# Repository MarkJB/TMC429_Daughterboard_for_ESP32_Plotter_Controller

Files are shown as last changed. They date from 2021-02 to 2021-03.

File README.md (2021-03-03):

# TMC429 Daughterboard for ESP32 Plotter Controller
 
Released under an MIT licence, no warranty implied or given, use at own risk etc etc.

This is an add-on (daughterboard) for the ESP32 Plotter Controller board (Rev A) to evaluate the TMC429 motion controller chip using the TMC429 Break-out-board.

Firmware TBD

[Schematic]( https://github.com/MarkJB/TMC429_Daughterboard_for_ESP32_Plotter_Controller/blob/master/schematic.pdf )

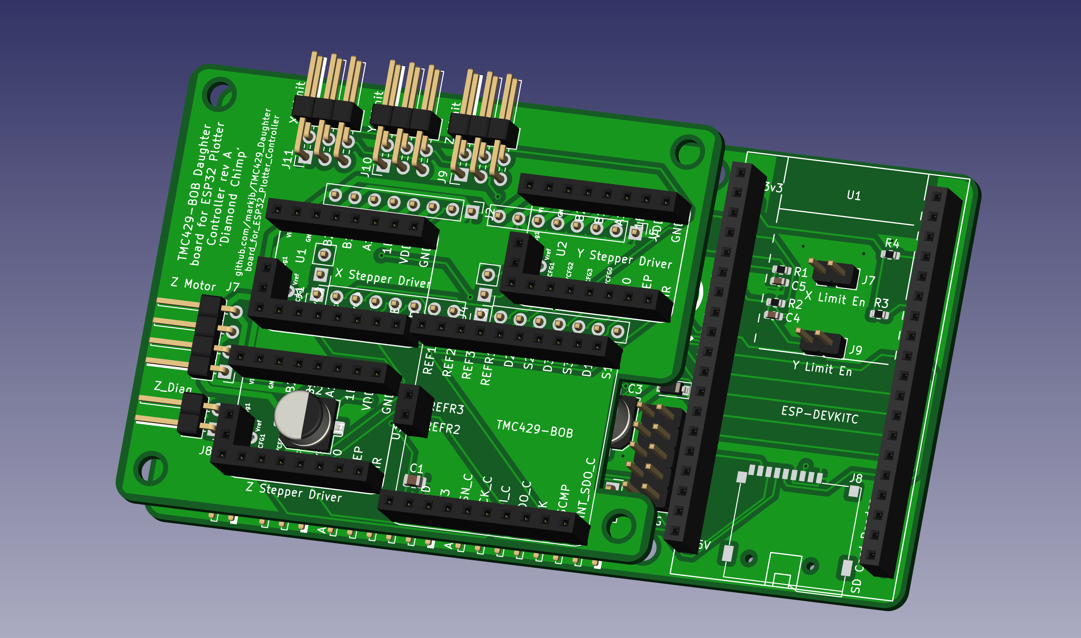
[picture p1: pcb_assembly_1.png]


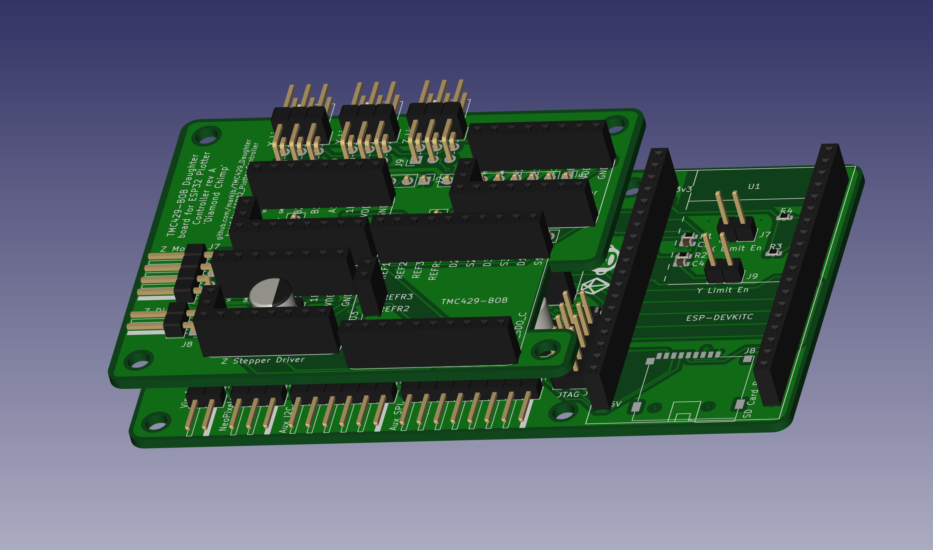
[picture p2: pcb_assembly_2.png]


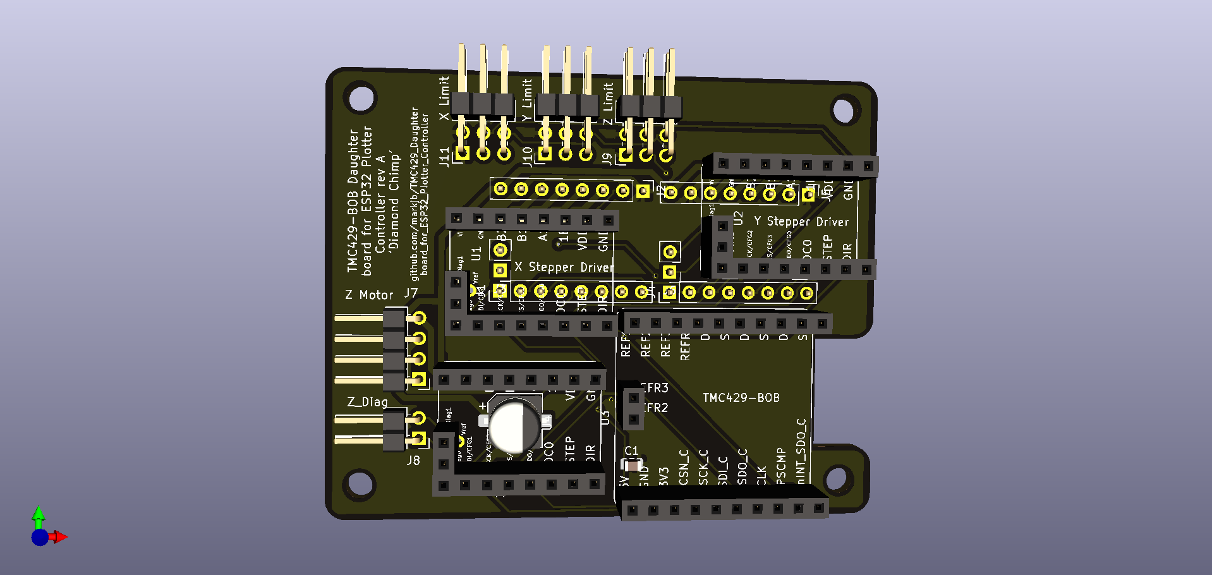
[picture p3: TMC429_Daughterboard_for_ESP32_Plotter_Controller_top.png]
Render of top of board


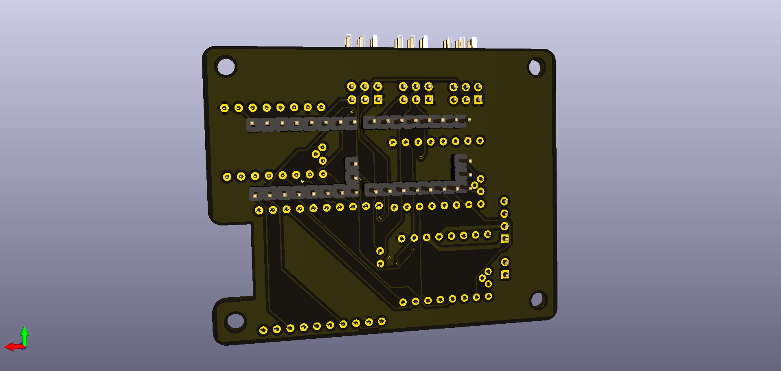
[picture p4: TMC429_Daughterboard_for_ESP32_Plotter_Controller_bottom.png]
Render of bottom of board


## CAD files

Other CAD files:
pcb_assembly.FCStd

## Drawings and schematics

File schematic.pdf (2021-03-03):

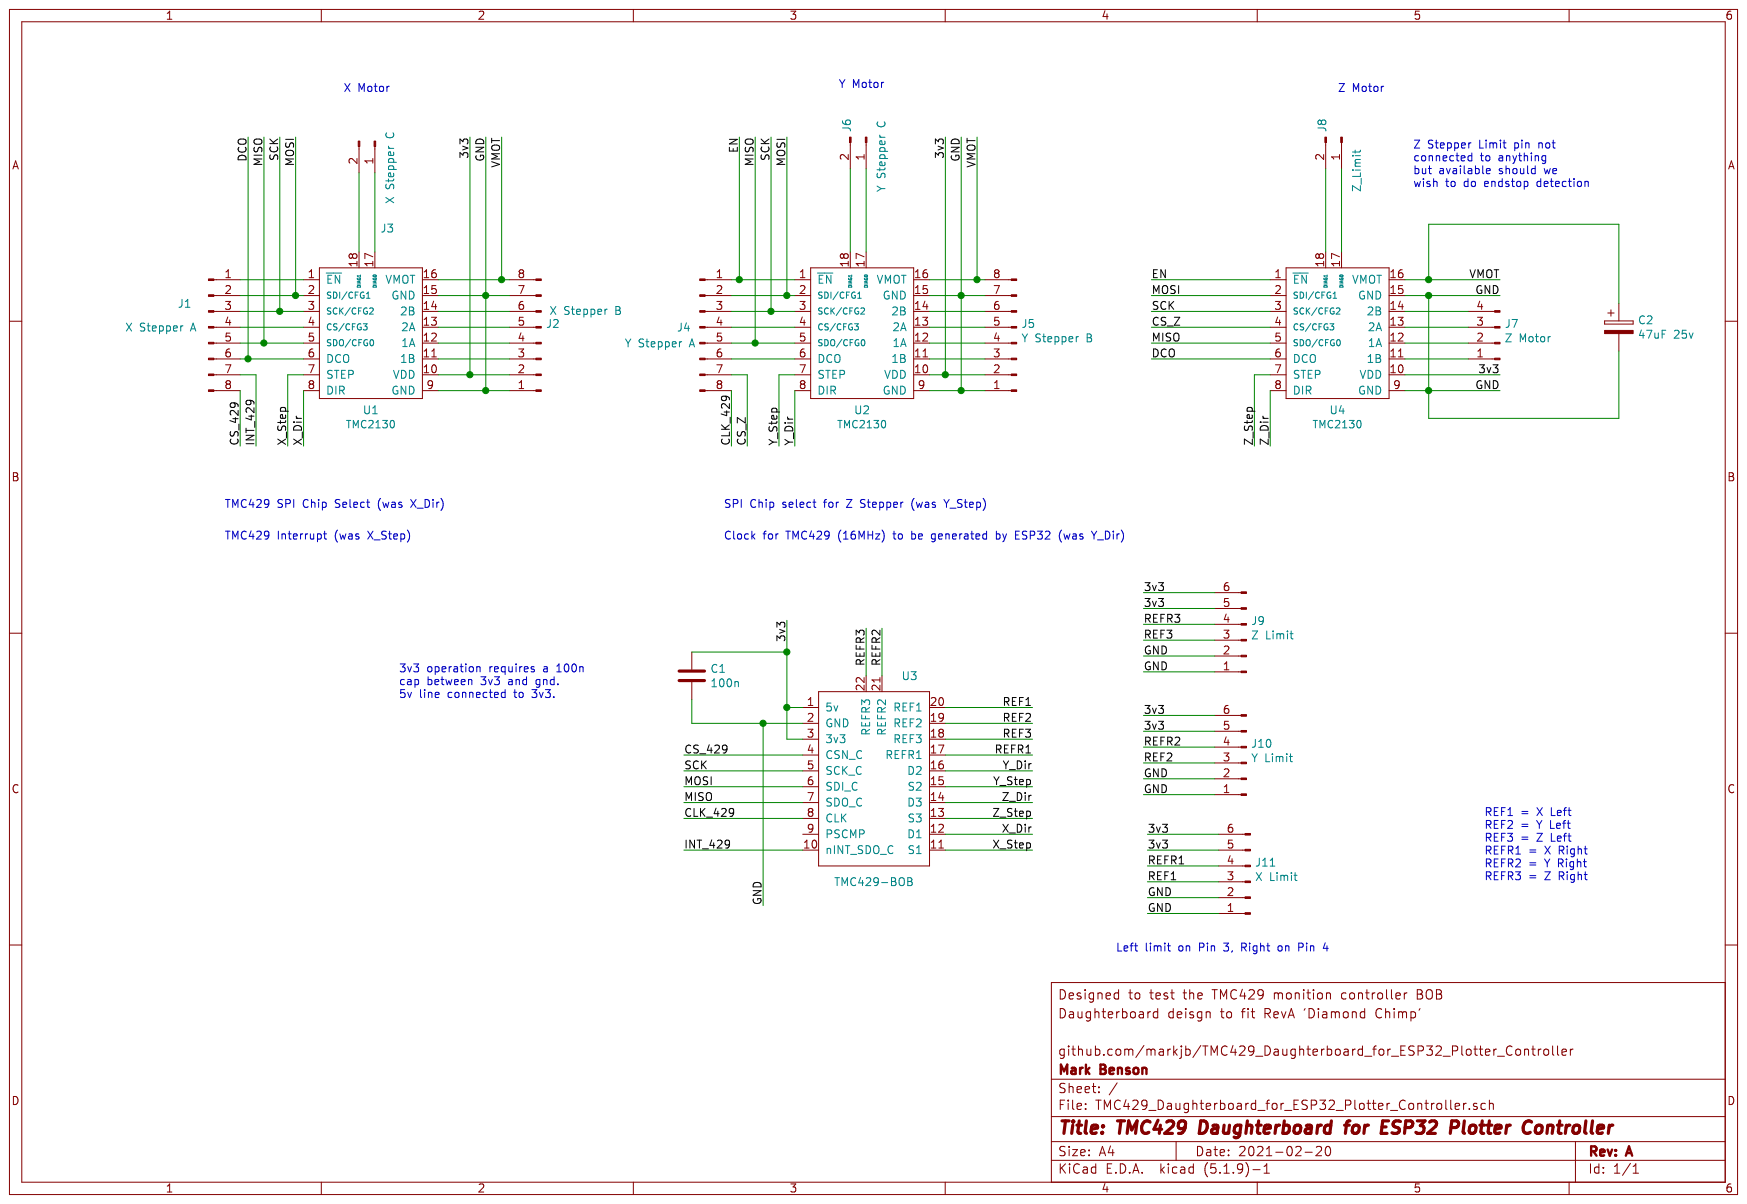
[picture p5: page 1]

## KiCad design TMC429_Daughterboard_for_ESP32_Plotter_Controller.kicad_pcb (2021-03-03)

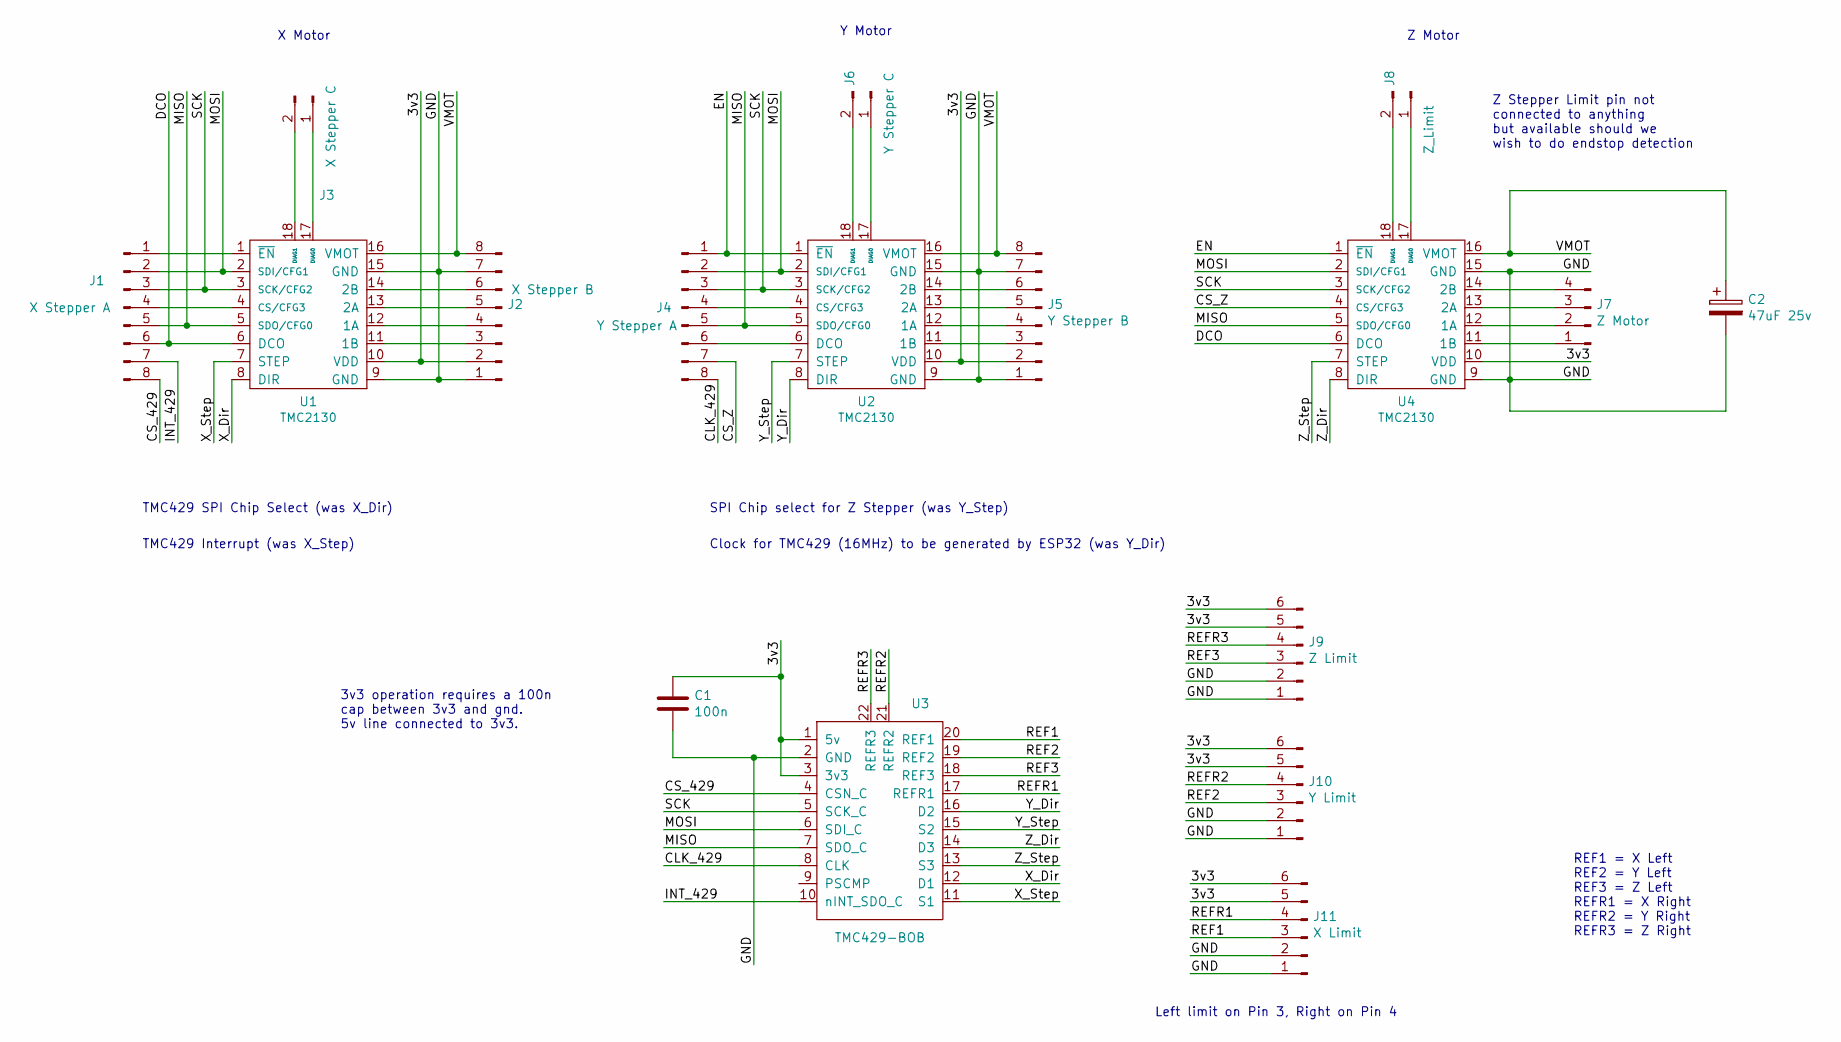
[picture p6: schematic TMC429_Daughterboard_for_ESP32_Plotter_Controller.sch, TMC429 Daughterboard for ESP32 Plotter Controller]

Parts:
C1: 100n; C_0805_2012Metric
C2: 47uF 25v; CP_Elec_6.3x5.4
J1: X Stepper A; PinHeader_1x08_P2.54mm_Vertical
J2: X Stepper B; PinHeader_1x08_P2.54mm_Vertical
J3: X Stepper C; PinHeader_1x02_P2.54mm_Vertical
J4: Y Stepper A; PinHeader_1x08_P2.54mm_Vertical
J5: Y Stepper B; PinHeader_1x08_P2.54mm_Vertical
J6: Y Stepper C; PinHeader_1x02_P2.54mm_Vertical
J7: Z Motor; PinHeader_1x04_P2.54mm_Horizontal
J8: Z_Limit; PinHeader_1x02_P2.54mm_Horizontal
J9: Z Limit; PinHeader_2x03_P2.54mm_Horizontal
J10: Y Limit; PinHeader_2x03_P2.54mm_Horizontal
J11: X Limit; PinHeader_2x03_P2.54mm_Horizontal
U1, U2, U4: TMC2130; StepstickTMCv2
U3: TMC429-BOB

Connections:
/3v3: C1.1, J2.2, J5.2, J9.5, J9.6, J10.5, J10.6, J11.5, J11.6, U1.10 (VDD), U2.10 (VDD), U3.1 (5v), U3.3 (3v3), U4.10 (VDD)
/CLK_429: J4.8, U3.8 (CLK)
/CS_429: J1.8, U3.4 (CSN_C)
/CS_Z: J4.7, U4.4 (CS/CFG3)
/DCO: J1.6, U1.6 (DCO), U4.6 (DCO)
/EN: J4.1, U2.1 (~EN), U4.1 (~EN)
/GND: C1.2, C2.2, J2.1, J2.7, J5.1, J5.7, J9.1, J9.2, J10.1, J10.2, J11.1, J11.2, U1.9 (GND), U1.15 (GND), U2.9 (GND), U2.15 (GND), U3.2 (GND), U4.9 (GND), U4.15 (GND)
/INT_429: J1.7, U3.10 (nINT_SDO_C)
/MISO: J1.5, J4.5, U1.5 (SDO/CFG0), U2.5 (SDO/CFG0), U3.7 (SDO_C), U4.5 (SDO/CFG0)
/MOSI: J1.2, J4.2, U1.2 (SDI/CFG1), U2.2 (SDI/CFG1), U3.6 (SDI_C), U4.2 (SDI/CFG1)
/REF1: J11.3, U3.20 (REF1)
/REF2: J10.3, U3.19 (REF2)
/REF3: J9.3, U3.18 (REF3)
/REFR1: J11.4, U3.17 (REFR1)
/REFR2: J10.4, U3.21 (REFR2)
/REFR3: J9.4, U3.22 (REFR3)
/SCK: J1.3, J4.3, U1.3 (SCK/CFG2), U2.3 (SCK/CFG2), U3.5 (SCK_C), U4.3 (SCK/CFG2)
/VMOT: C2.1, J2.8, J5.8, U1.16 (VMOT), U2.16 (VMOT), U4.16 (VMOT)
/X_Dir: U1.8 (DIR), U3.12 (D1)
/X_Step: U1.7 (STEP), U3.11 (S1)
/Y_Dir: U2.8 (DIR), U3.16 (D2)
/Y_Step: U2.7 (STEP), U3.15 (S2)
/Z_Dir: U3.14 (D3), U4.8 (DIR)
/Z_Step: U3.13 (S3), U4.7 (STEP)
unnamed: J1.1, U1.1 (~EN)
unnamed: J1.4, U1.4 (CS/CFG3)
unnamed: J2.3, U1.11 (1B)
unnamed: J2.4, U1.12 (1A)
unnamed: J2.5, U1.13 (2A)
unnamed: J2.6, U1.14 (2B)
unnamed: J3.1, U1.17 (DIAG0)
unnamed: J3.2, U1.18 (DIAG1)
unnamed: J4.4, U2.4 (CS/CFG3)
unnamed: J4.6, U2.6 (DCO)
unnamed: J5.3, U2.11 (1B)
unnamed: J5.4, U2.12 (1A)
unnamed: J5.5, U2.13 (2A)
unnamed: J5.6, U2.14 (2B)
unnamed: J6.1, U2.17 (DIAG0)
unnamed: J6.2, U2.18 (DIAG1)
unnamed: J7.1, U4.11 (1B)
unnamed: J7.2, U4.12 (1A)
unnamed: J7.3, U4.13 (2A)
unnamed: J7.4, U4.14 (2B)
unnamed: J8.1, U4.17 (DIAG0)
unnamed: J8.2, U4.18 (DIAG1)

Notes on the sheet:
X Motor
Y Motor
Left limit on Pin 3, Right on Pin 4
REF1 = X Left REF2 = Y Left REF3 = Z Left REFR1 = X Right REFR2 = Y Right REFR3 = Z Right
TMC429 SPI Chip Select (was X_Dir)
TMC429 Interrupt (was X_Step)
3v3 operation requires a 100n cap between 3v3 and gnd. 5v line connected to 3v3.
Z Motor
Clock for TMC429 (16MHz) to be generated by ESP32 (was Y_Dir)
SPI Chip select for Z Stepper (was Y_Step)
Z Stepper Limit pin not connected to anything but available should we wish to do endstop detection

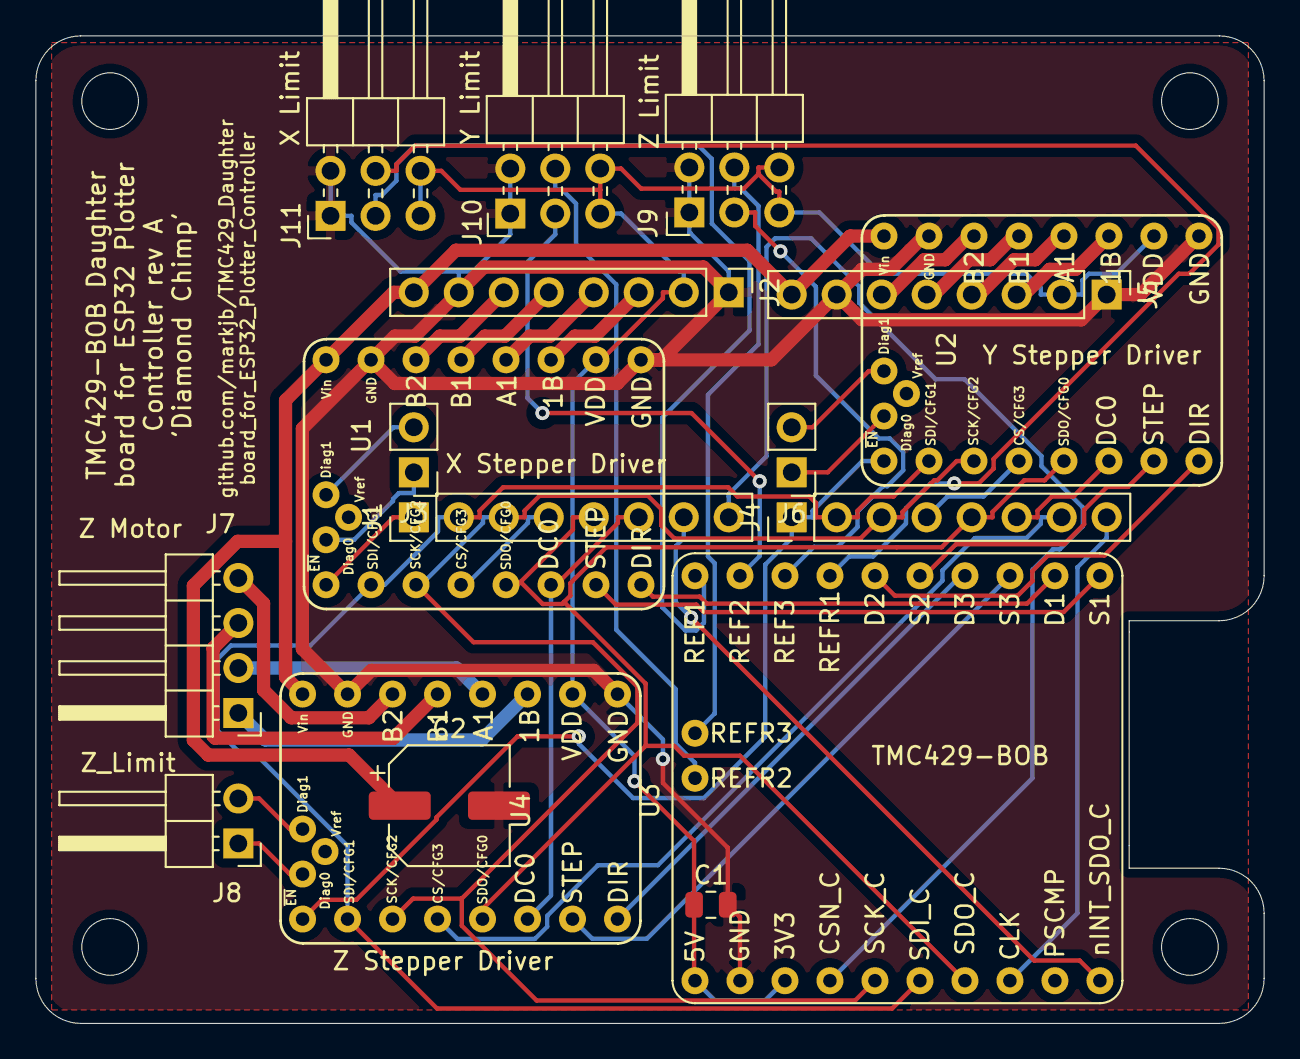
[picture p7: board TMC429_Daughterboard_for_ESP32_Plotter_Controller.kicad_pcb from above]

Board: 2 copper layers, 69.3 x 55.8 mm, 21 parts (0 on the bottom side), 46 nets.

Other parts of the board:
H1, H2, H3, H4: MountingHole_3.2mm_M3
